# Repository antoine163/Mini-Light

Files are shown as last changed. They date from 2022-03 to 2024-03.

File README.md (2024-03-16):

# Mini Light
This is a small brightness control for desktop / workbench  / ... 
This is composed several parts:
- The control box: To enclose the power supply/electronic and sliders control.
- Light support for shelf: To attach the lights under shelf.
- Light support for prusa: To attach the lights  on prusa 3D printer.
- Wire Ties: To attach some cables.

## Control box
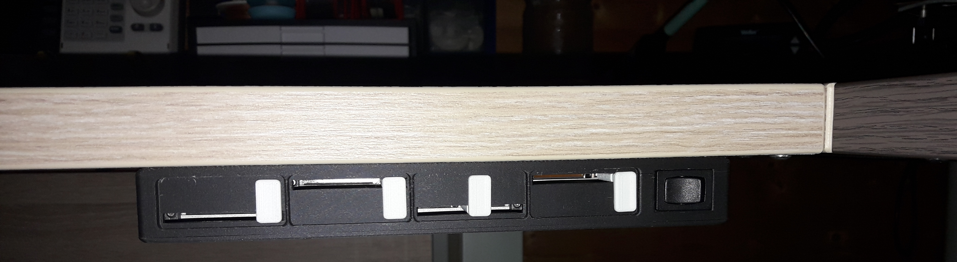
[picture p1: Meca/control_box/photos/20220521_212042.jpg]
 
For more detail see: [Meca/control_box/README.md](Meca/control_box/README.md) 

## Light support for shelf
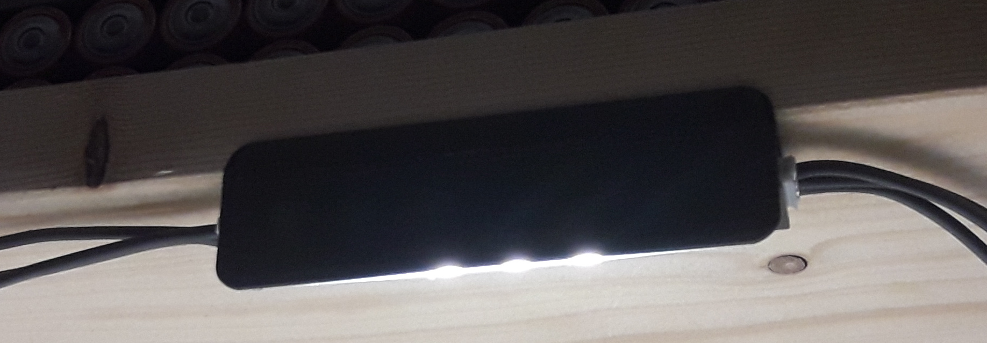
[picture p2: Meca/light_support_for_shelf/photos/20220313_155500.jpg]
 
For more detail see: [Meca/light_support_for_shelf/README.md](Meca/light_support_for_shelf/README.md) 

## Light support for prusa
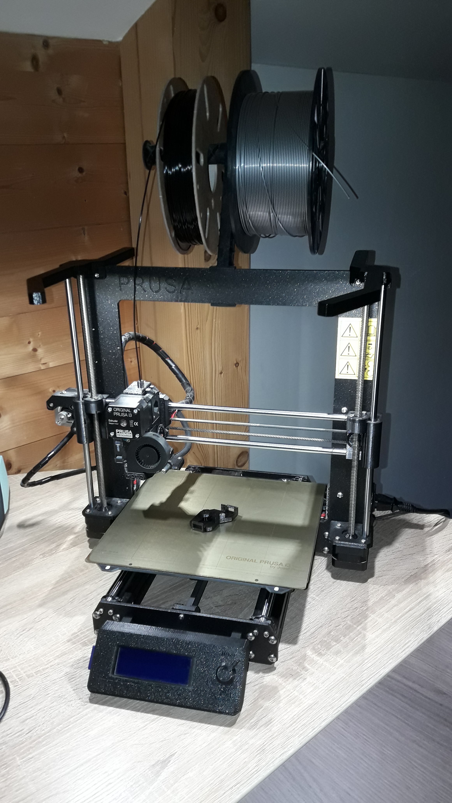
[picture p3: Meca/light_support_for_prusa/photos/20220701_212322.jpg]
 
For more detail see: [Meca/light_support_for_shelf/README.md](Meca/light_support_for_prusa/README.md) 

# 3D Models
Some 3D models are not included in this project. You will need to download them from the manufacturers website if you need them.

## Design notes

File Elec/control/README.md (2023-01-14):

# Mini-Light-Control Board
This board can be power and control 4 different cluster of mini_light board.

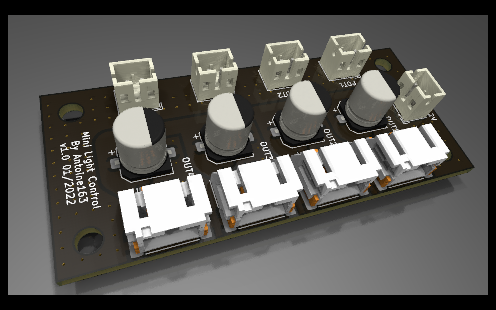
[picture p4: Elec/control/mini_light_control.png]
mini_light_control
 

# Schematic


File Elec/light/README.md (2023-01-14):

# Mini-Light Board
This board is a mini_light board.

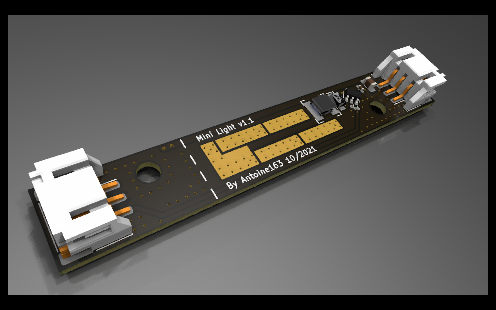
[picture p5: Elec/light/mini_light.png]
mini_light_control
 

Consumption max: 1.8W 

# Schematic


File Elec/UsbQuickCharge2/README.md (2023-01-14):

# Usb Quick Charge 2.0

Circuit To enables 12V power on a USB Quick Charge 2.0 interface.
And brightness adjustment for Mini-Light.

# Schematic


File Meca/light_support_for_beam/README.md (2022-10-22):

# Mini light: Light support for beam
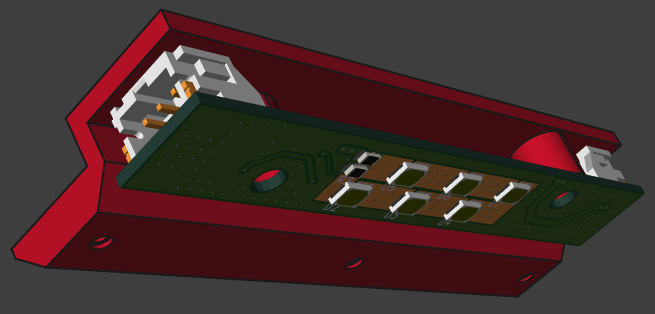
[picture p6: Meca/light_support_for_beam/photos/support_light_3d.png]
Front view
 

## How to build
### List of items to found
- Some wires: [Amazon](https://www.amazon.fr/gp/product/B07G72FZCR/ref=ppx_od_dt_b_asin_title_s00?ie=UTF8&psc=1), [Farnell](https://fr.farnell.com/lapp-kabel/0047001/fil-silicone-0-25mm-noir-100m/dp/1285908) 
- Some JST connectors, PH series: [Amazon](https://www.amazon.fr/gp/product/B07SN5DLWH/ref=ppx_od_dt_b_asin_title_s00?ie=UTF8&psc=1)
- Some M3 threaded inser: [Amazon](https://www.amazon.fr/gp/product/B08BCRZZS3/ref=ppx_yo_dt_b_asin_title_o02_s00?ie=UTF8&psc=1)
- Some M3 Screws: [Amazon](https://www.amazon.fr/gp/product/B07ZF2SDW6/ref=ppx_yo_dt_b_asin_title_o00_s00?ie=UTF8&psc=1)

### List of board to build
- 1x light board. See: [Elec/light/README.md](../../Elec/light/README.md) 

### List of 3D printed parts
- 1x support_light

All 3D parts in .stl format are in to **"stl"** folder. In the folder **"prusa-slicer"** you can found the project of prusa-slicer.

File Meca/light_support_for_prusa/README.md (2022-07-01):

# Mini light: Light support for prusa mk3
Front view 
**Note:** The fixing is inspired by the prject [LED Light Bar Prusa i3 MK2/MK3](https://www.printables.com/fr/model/3267-led-light-bar-prusa-i3-mk2mk3) 

## How to build
### List of items to found
- Some wires: [Amazon](https://www.amazon.fr/gp/product/B07G72FZCR/ref=ppx_od_dt_b_asin_title_s00?ie=UTF8&psc=1), [Farnell](https://fr.farnell.com/lapp-kabel/0047001/fil-silicone-0-25mm-noir-100m/dp/1285908) 
- Some JST connectors, PH series: [Amazon](https://www.amazon.fr/gp/product/B07SN5DLWH/ref=ppx_od_dt_b_asin_title_s00?ie=UTF8&psc=1)
- Some M3 threaded inser: [Amazon](https://www.amazon.fr/gp/product/B08BCRZZS3/ref=ppx_yo_dt_b_asin_title_o02_s00?ie=UTF8&psc=1)
- Some M3 Screws: [Amazon](https://www.amazon.fr/gp/product/B07ZF2SDW6/ref=ppx_yo_dt_b_asin_title_o00_s00?ie=UTF8&psc=1)

### List of board to build
- 4x light boards. See: [Elec/light/README.md](../../Elec/light/README.md) 

### List of 3D printed parts
- 1x support_light_l.stl
- 1x support_light_nut_r.stl
- 1x support_light_nut_l.stl
- 1x support_light_r.stl

All 3D parts in .stl format are in to **"stl"** folder. In the folder **"prusa-slicer"** you can found the project of prusa-slicer.

## Photo to help build
### List of wire to cut
- 6x 2cm
- 6x 14cm
- 3x 32cm

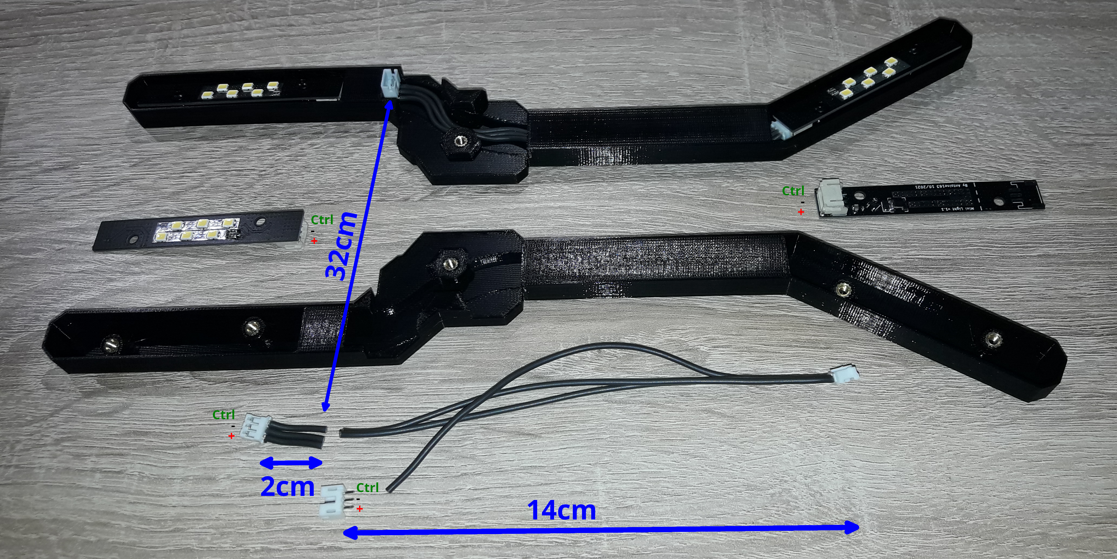
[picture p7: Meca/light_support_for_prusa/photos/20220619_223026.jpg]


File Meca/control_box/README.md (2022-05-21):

# Mini light: Control box
Front view 
Another view with a slider (control_box-AsPotsCap) in v1:
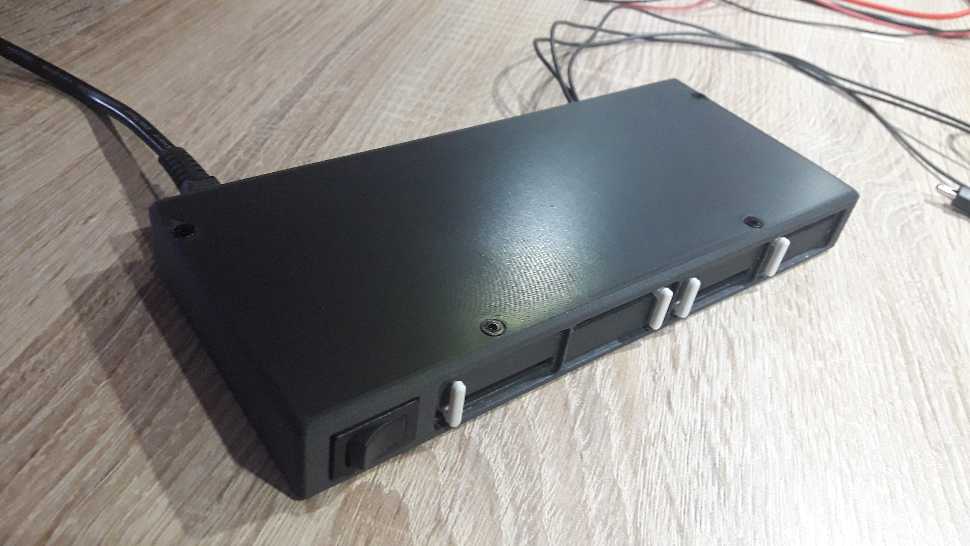
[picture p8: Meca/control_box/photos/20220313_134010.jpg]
 
## How to build
### List of items to found
- 1x IEC320 C7 cable.
- 1x IEC320 C7 connecter: [Amazon](https://www.amazon.fr/gp/product/B08TWM1LQ6/ref=ppx_yo_dt_b_asin_title_o00_s00?ie=UTF8&psc=1) 
- 1x Toggle Swith 230V (Multicomp: MP004405): [Farnell](https://fr.farnell.com/multicomp-pro/mp004405/commut-spst-10a-250vac-noir-panneau/dp/3462082) 
- 1x 230V to 12V Power module: [Amazon](https://www.amazon.fr/gp/product/B0924XBMCF/ref=ppx_yo_dt_b_asin_title_o01_s00?ie=UTF8&th=1) 
- 1x to 4x 50K slide potentiometers (Alps Alpine: STRS30102K): [Farnell](https://fr.farnell.com/alps/strs30102k/potentiometre-slide-50k/dp/1191729) 
- Some wires: [Amazon](https://www.amazon.fr/gp/product/B07G72FZCR/ref=ppx_od_dt_b_asin_title_s00?ie=UTF8&psc=1), [Farnell](https://fr.farnell.com/lapp-kabel/0047001/fil-silicone-0-25mm-noir-100m/dp/1285908) , **Note**: For wires connected at sector power use appropriate wires, I don't sure that wire is usable for this!
- Some JST connectors, PH series: [Amazon](https://www.amazon.fr/gp/product/B07SN5DLWH/ref=ppx_od_dt_b_asin_title_s00?ie=UTF8&psc=1), **Note**: The box for SMT is unavailable now
- Some M3 threaded inser: [Amazon](https://www.amazon.fr/gp/product/B08BCRZZS3/ref=ppx_yo_dt_b_asin_title_o02_s00?ie=UTF8&psc=1)
- Some M3 Screws: [Amazon](https://www.amazon.fr/gp/product/B07ZF2SDW6/ref=ppx_yo_dt_b_asin_title_o00_s00?ie=UTF8&psc=1)
- Some M2 Screws and nut: [Amazon](https://www.amazon.fr/gp/product/B093BY1XJJ/ref=ppx_yo_dt_b_asin_title_o02_s00?ie=UTF8&psc=1)

### List of board to build
- 1x Mini light control board. See: [Elec/control/README.md](../../Elec/control/README.md) 

### List of 3D printed parts
- 1x control_box-AsPotsCap_v2 (or control_box-AsPotsCap)
- 1x control_box-control_box
- 1x control_box-control_box_lid
- 1x control_box-Fix1_Power_Supply
- 1x control_box-Fix2_Power_Supply
- 4x control_box-SupPot

All 3D parts in .stl format are in to **"stl"** folder. In the folder **"prusa-slicer"** you can found the project of prusa-slicer.

## Photos to help build
**Note**: One the photos below there are only two sliders connected and control_box-AsPotsCap is in v1.
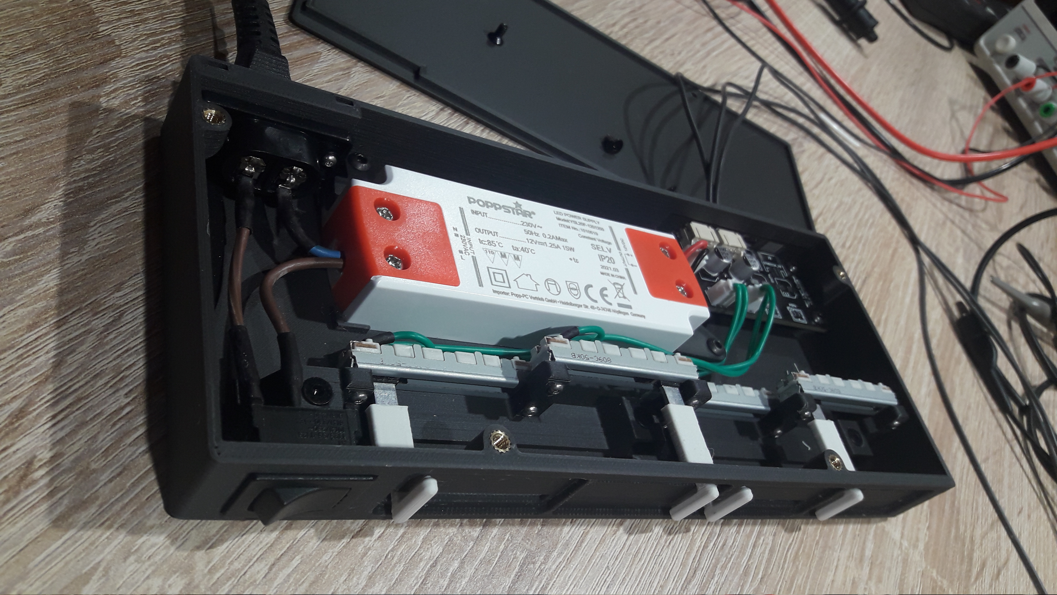
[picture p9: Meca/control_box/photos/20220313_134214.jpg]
 
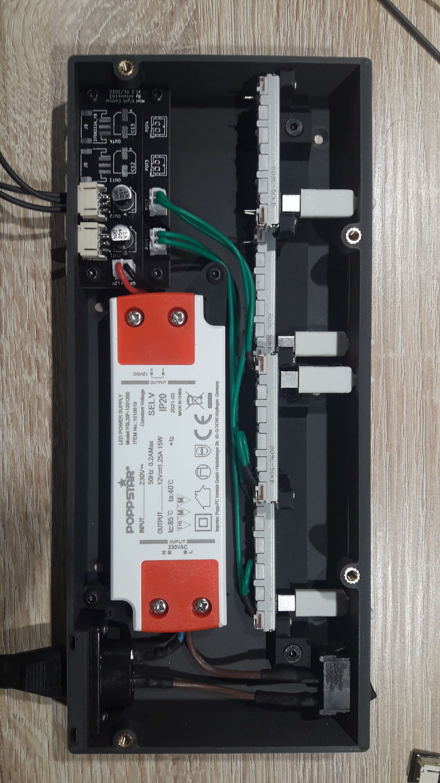
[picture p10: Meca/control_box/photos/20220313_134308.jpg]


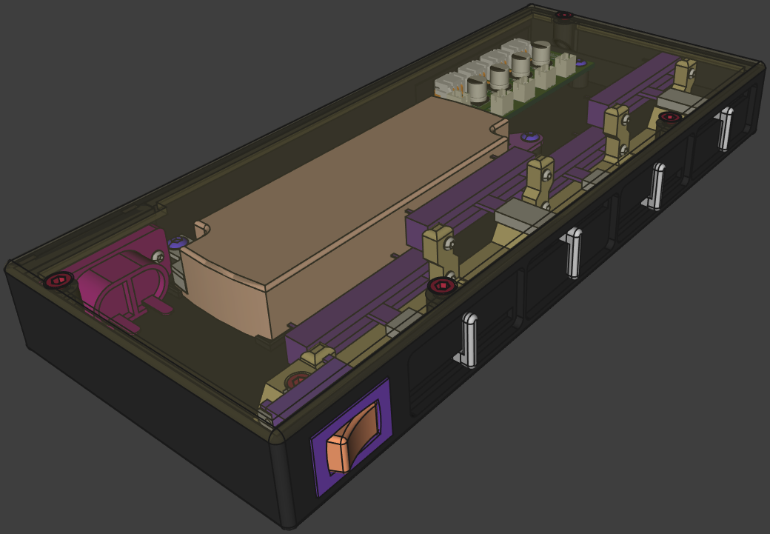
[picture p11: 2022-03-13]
Meca/control_box/front_view.png

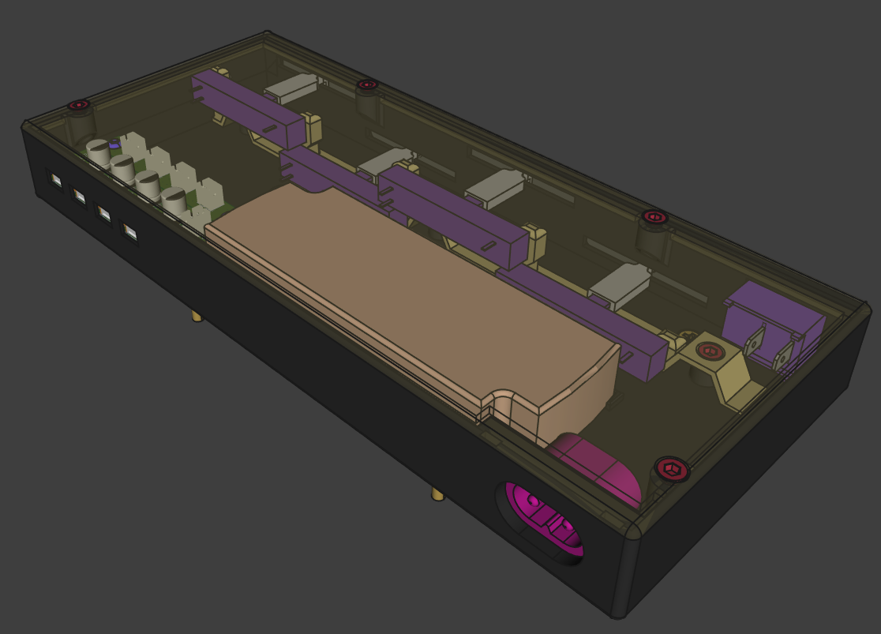
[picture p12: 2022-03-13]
Meca/control_box/rear_view.png

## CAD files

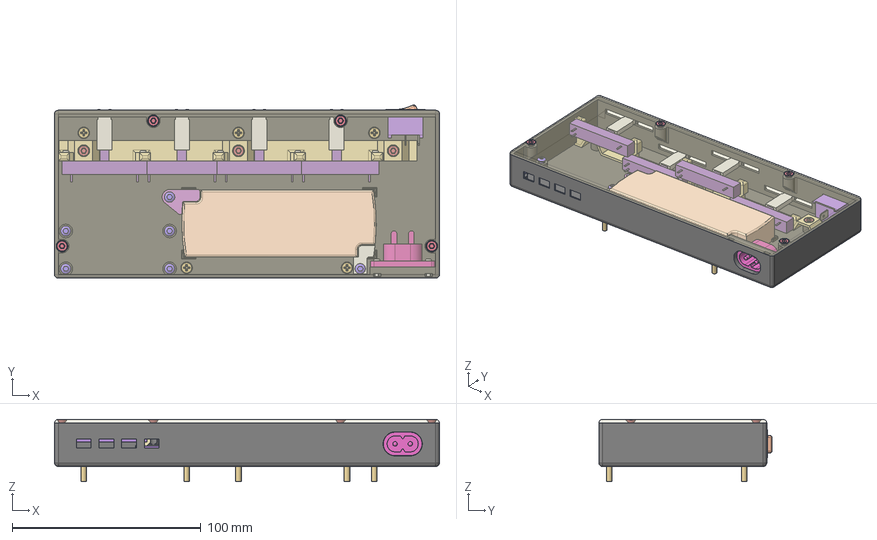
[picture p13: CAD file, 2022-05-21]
Meca/control_box/control_box.FCStd
204.0 x 91.9 x 33.0 mm
Poppstar_Power_Supply
conn1 x 2
switche
SupPot
Cap_1 x 4
STRS30102K_1 x 4
M2x6 x 8
Fix1_Power_Supply
Fix2_Power_Supply
IEC320_C7
M2x8 x 2
M3x10_Wood x 5
M3x4_Flat x 7
M3x6_Button x 6
control_box
control_box_lid

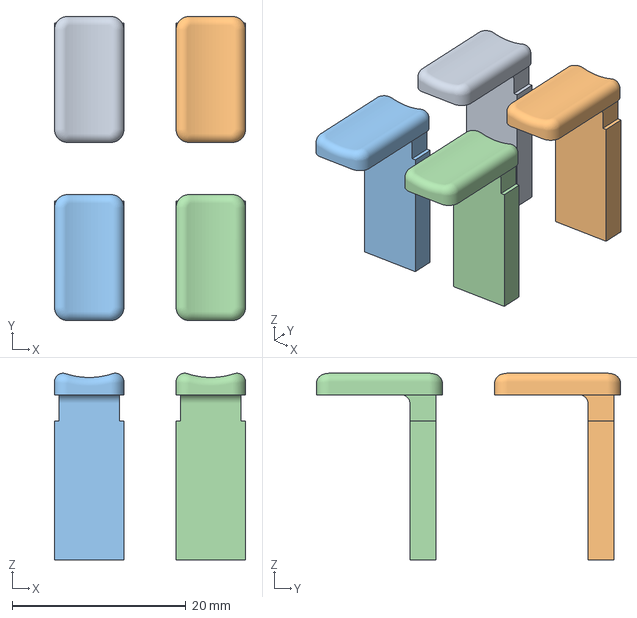
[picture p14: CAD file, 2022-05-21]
Meca/control_box/prusa-slicer/control_box-AsPotsCap_v2.3mf
22.0 x 35.0 x 21.5 mm

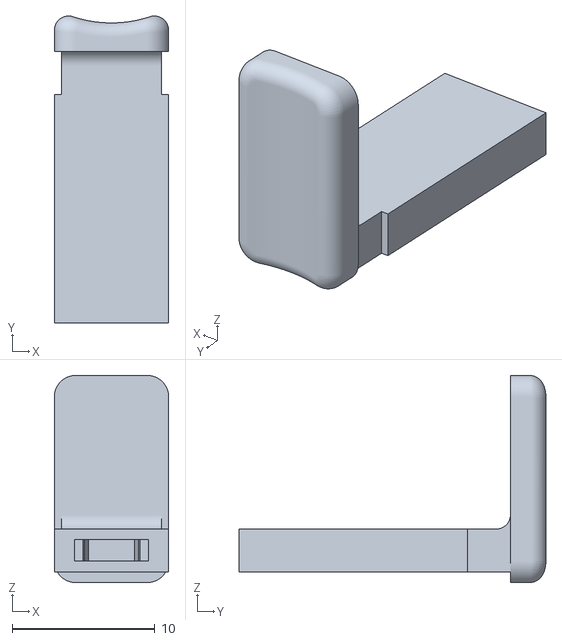
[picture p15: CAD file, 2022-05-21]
Meca/control_box/stl/control_box-AsPotsCap_v2.stl
8.00 x 21.5 x 14.5

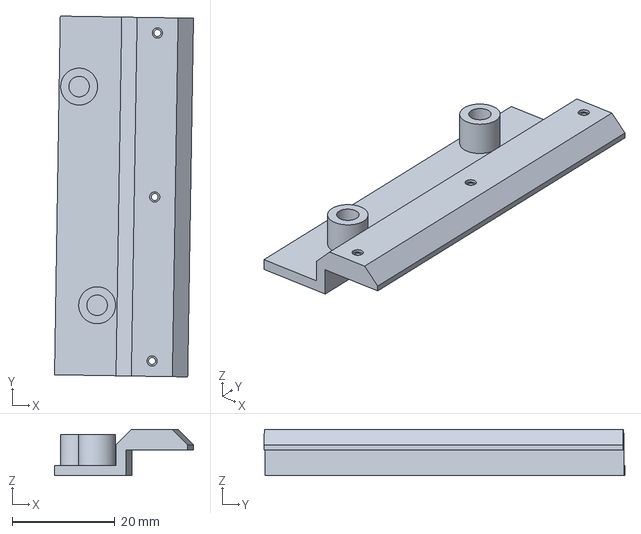
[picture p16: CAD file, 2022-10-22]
Meca/light_support_for_beam/prusa-slicer/support_light.3mf
27.1 x 70.4 x 9.00 mm

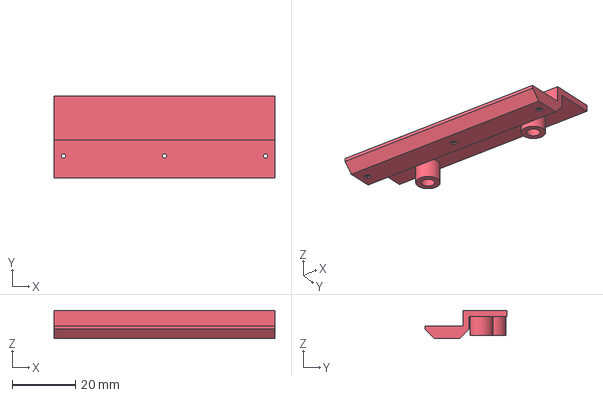
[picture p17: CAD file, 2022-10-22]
Meca/light_support_for_beam/support_light.FCStd
70.0 x 26.0 x 9.00 mm

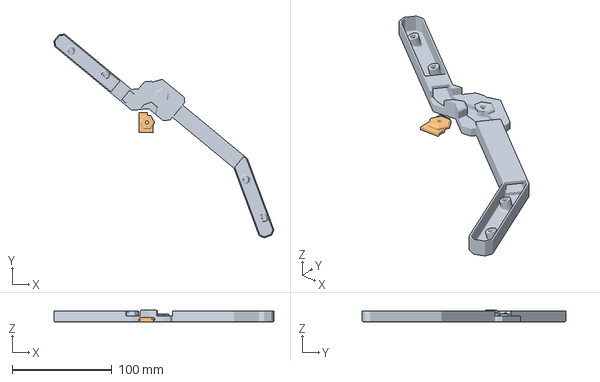
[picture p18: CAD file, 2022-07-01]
Meca/light_support_for_prusa/prusa-slicer/support_light_l.3mf
220.4 x 204.2 x 12.1 mm
support_light_l.stl
support_light_nut_l.stl

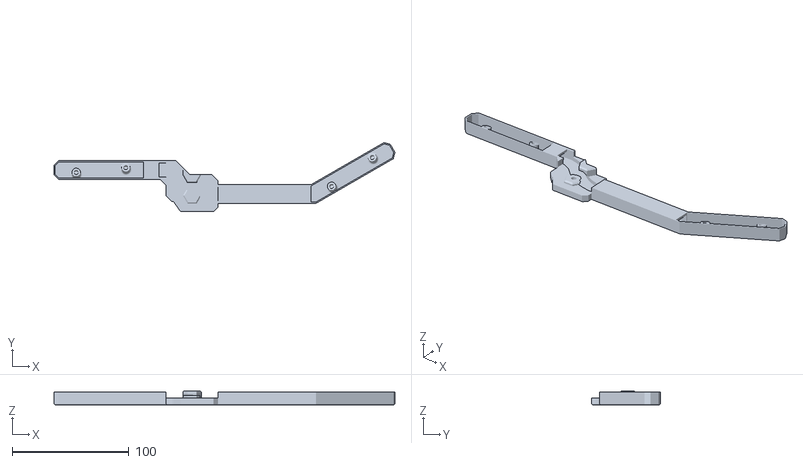
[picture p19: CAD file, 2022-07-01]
Meca/light_support_for_prusa/stl/support_light_r.stl
292.1 x 59.0 x 12.1

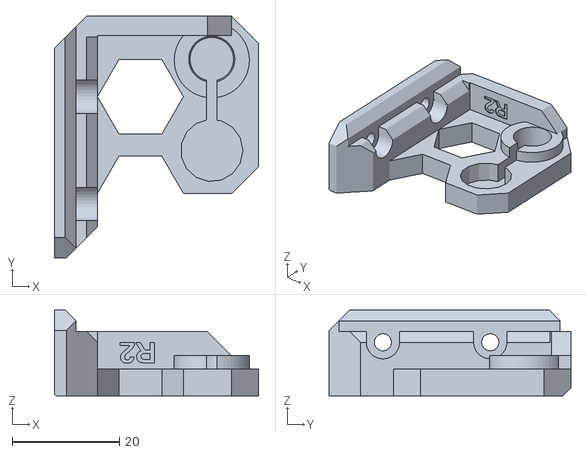
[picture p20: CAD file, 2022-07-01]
Meca/light_support_for_prusa/z-axis-top_l.stl
38.0 x 45.0 x 16.0

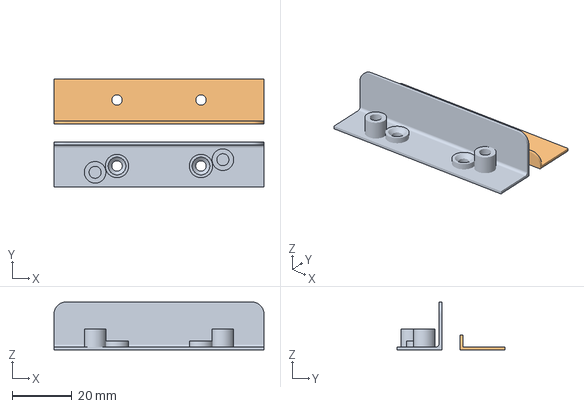
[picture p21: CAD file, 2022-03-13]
Meca/light_support_for_shelf/prusa-slicer/support_light.3mf
70.0 x 36.0 x 16.0 mm
support_light_part1.stl
support_light_part2.stl

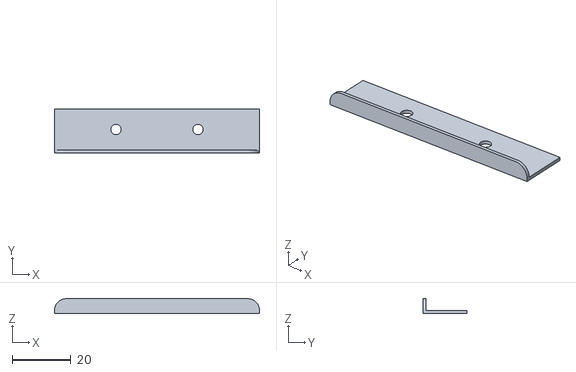
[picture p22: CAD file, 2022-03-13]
Meca/light_support_for_shelf/stl/support_light_part2.stl
70.0 x 15.0 x 5.00

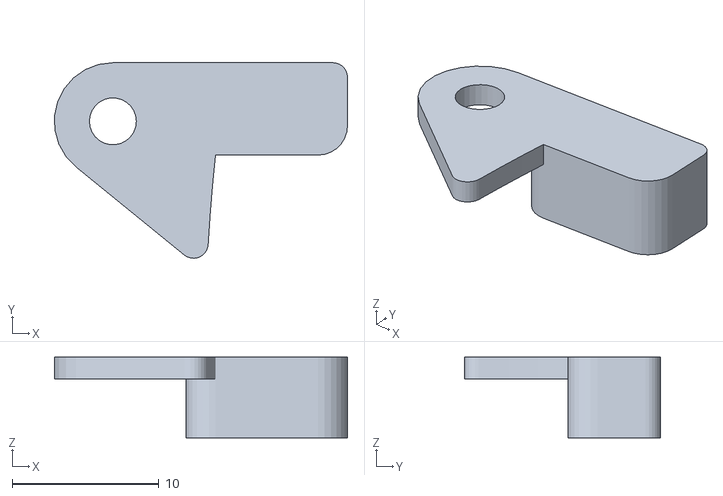
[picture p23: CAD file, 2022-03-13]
Meca/control_box/stl/control_box-Fix1_Power_Supply.stl
20.0 x 13.3 x 5.50

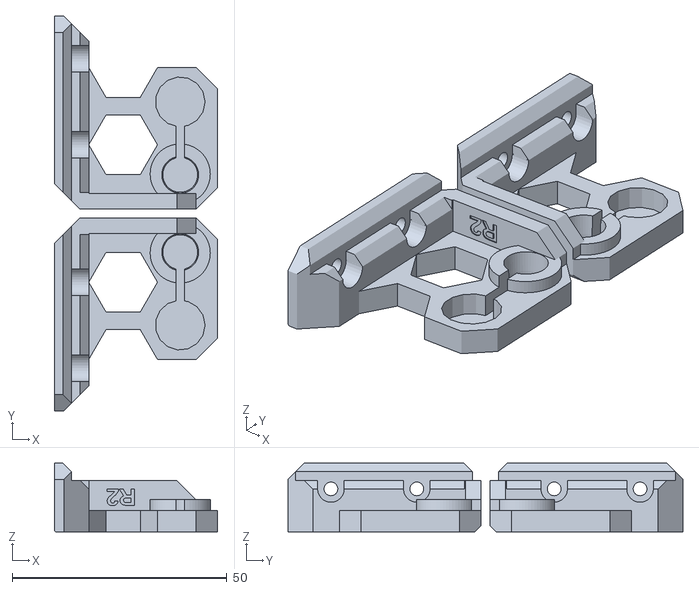
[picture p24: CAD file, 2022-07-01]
Meca/light_support_for_prusa/z-axis-top.stl
38.0 x 92.0 x 16.0

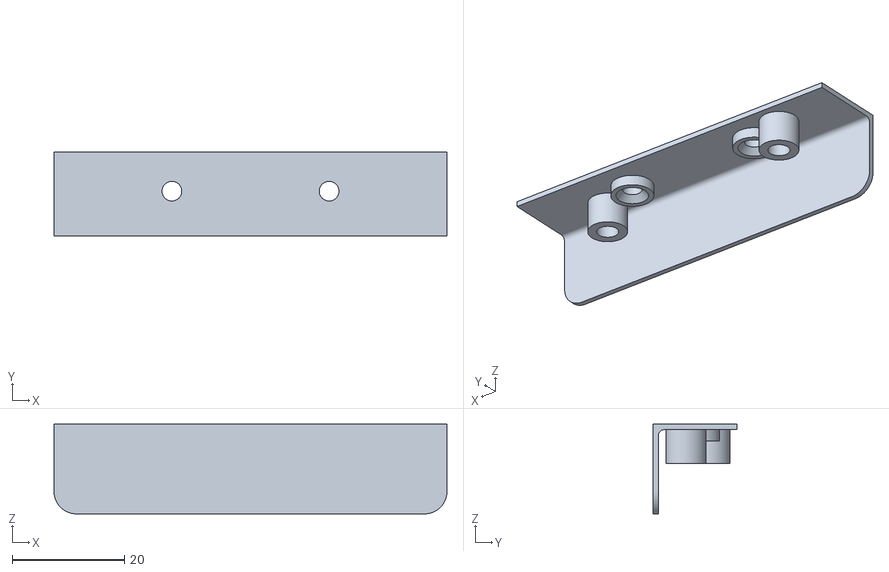
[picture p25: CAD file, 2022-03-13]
Meca/light_support_for_shelf/stl/support_light_part1.stl
70.0 x 15.0 x 16.0

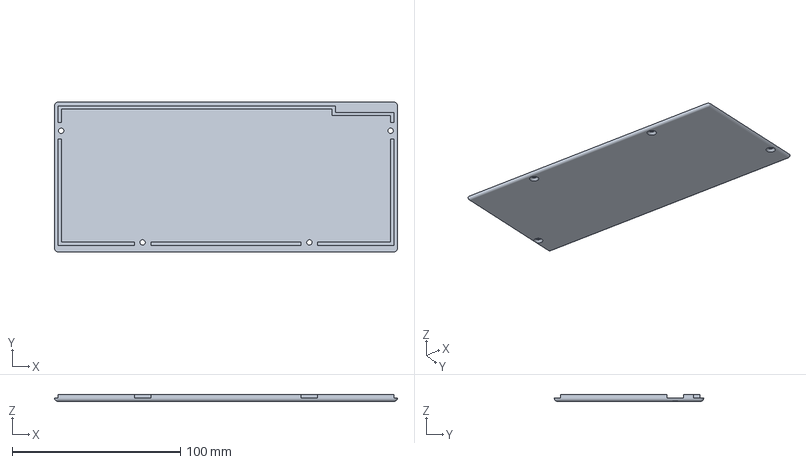
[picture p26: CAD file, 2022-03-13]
Meca/control_box/prusa-slicer/control_box-control_box_lid.3mf
204.0 x 89.0 x 4.00 mm

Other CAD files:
Meca/light_support_for_prusa/prusa-slicer/support_light_r.3mf
Meca/control_box/stl/control_box-control_box_lid.stl
Meca/light_support_for_prusa/z-axis-top_r.stl
Meca/control_box/prusa-slicer/control_box-control_box.3mf
Meca/control_box/prusa-slicer/control_box-AsPotsCap.3mf
Meca/control_box/prusa-slicer/control_box-Fix_Power_Supply.3mf
Meca/control_box/prusa-slicer/control_box-SupPot.3mf
Meca/control_box/stl/control_box-AsPotsCap.stl
Meca/control_box/stl/control_box-Fix2_Power_Supply.stl
Meca/control_box/stl/control_box-SupPot.stl
Meca/control_box/stl/control_box-control_box.stl
Meca/light_support_for_beam/stl/support_light.stl
Meca/light_support_for_prusa/mini_light.step
Meca/light_support_for_prusa/stl/support_light_l.stl
Meca/light_support_for_prusa/stl/support_light_nut_l.stl
Meca/light_support_for_prusa/stl/support_light_nut_r.stl
Meca/light_support_for_shelf/support_light.FCStd

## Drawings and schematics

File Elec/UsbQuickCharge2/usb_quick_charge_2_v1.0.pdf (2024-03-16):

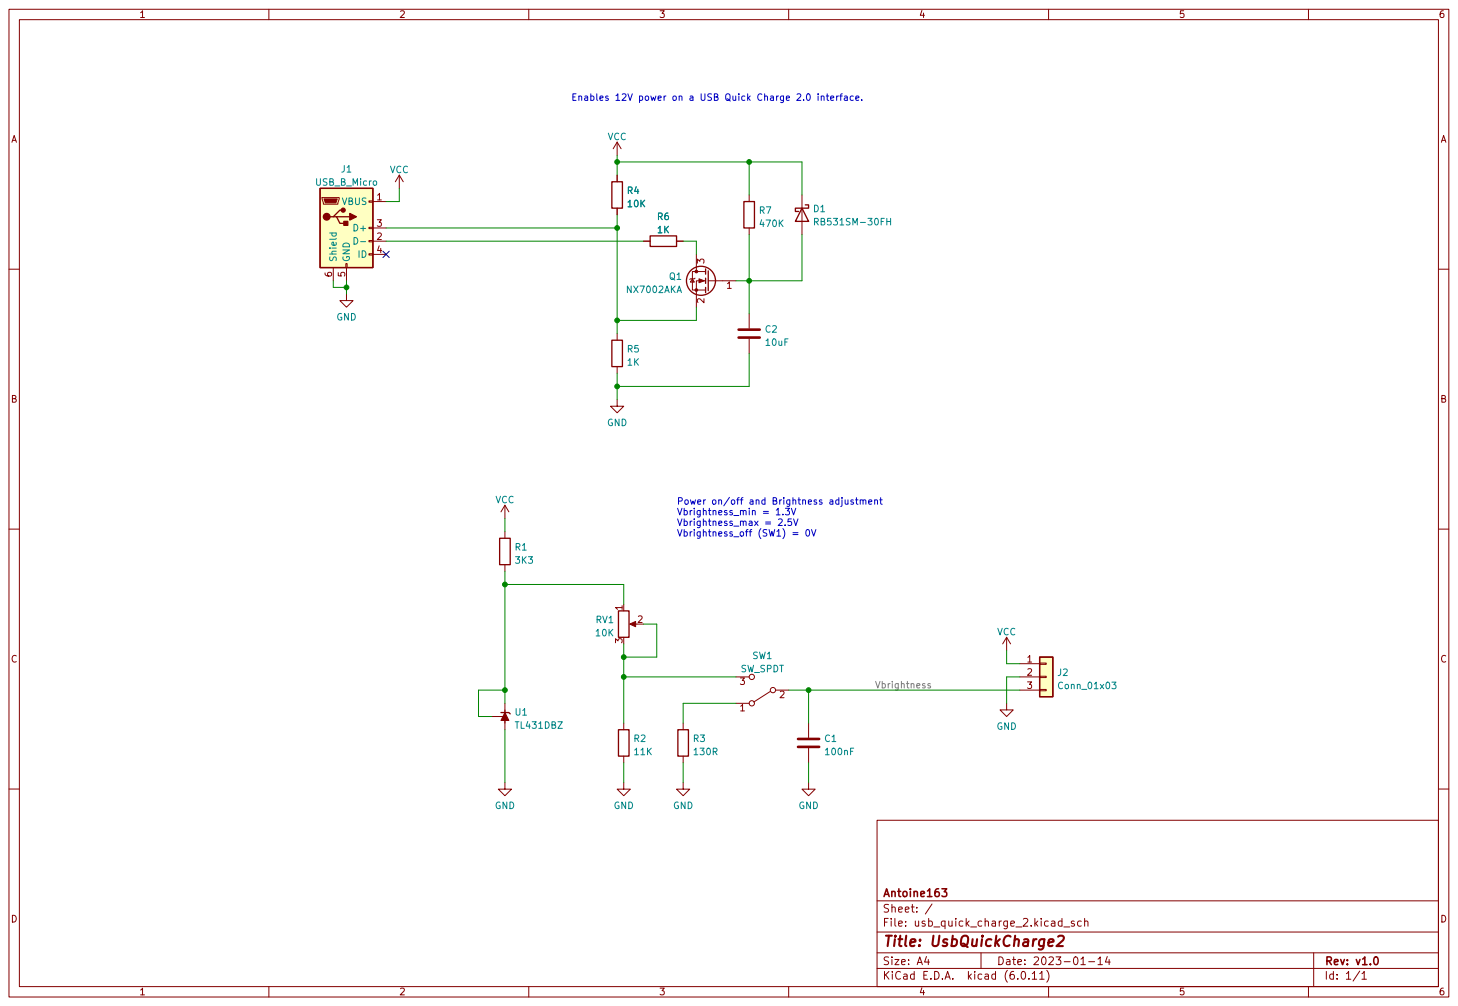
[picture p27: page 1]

Enables 12V power on a USB Quick Charge 2.0 interface. R6

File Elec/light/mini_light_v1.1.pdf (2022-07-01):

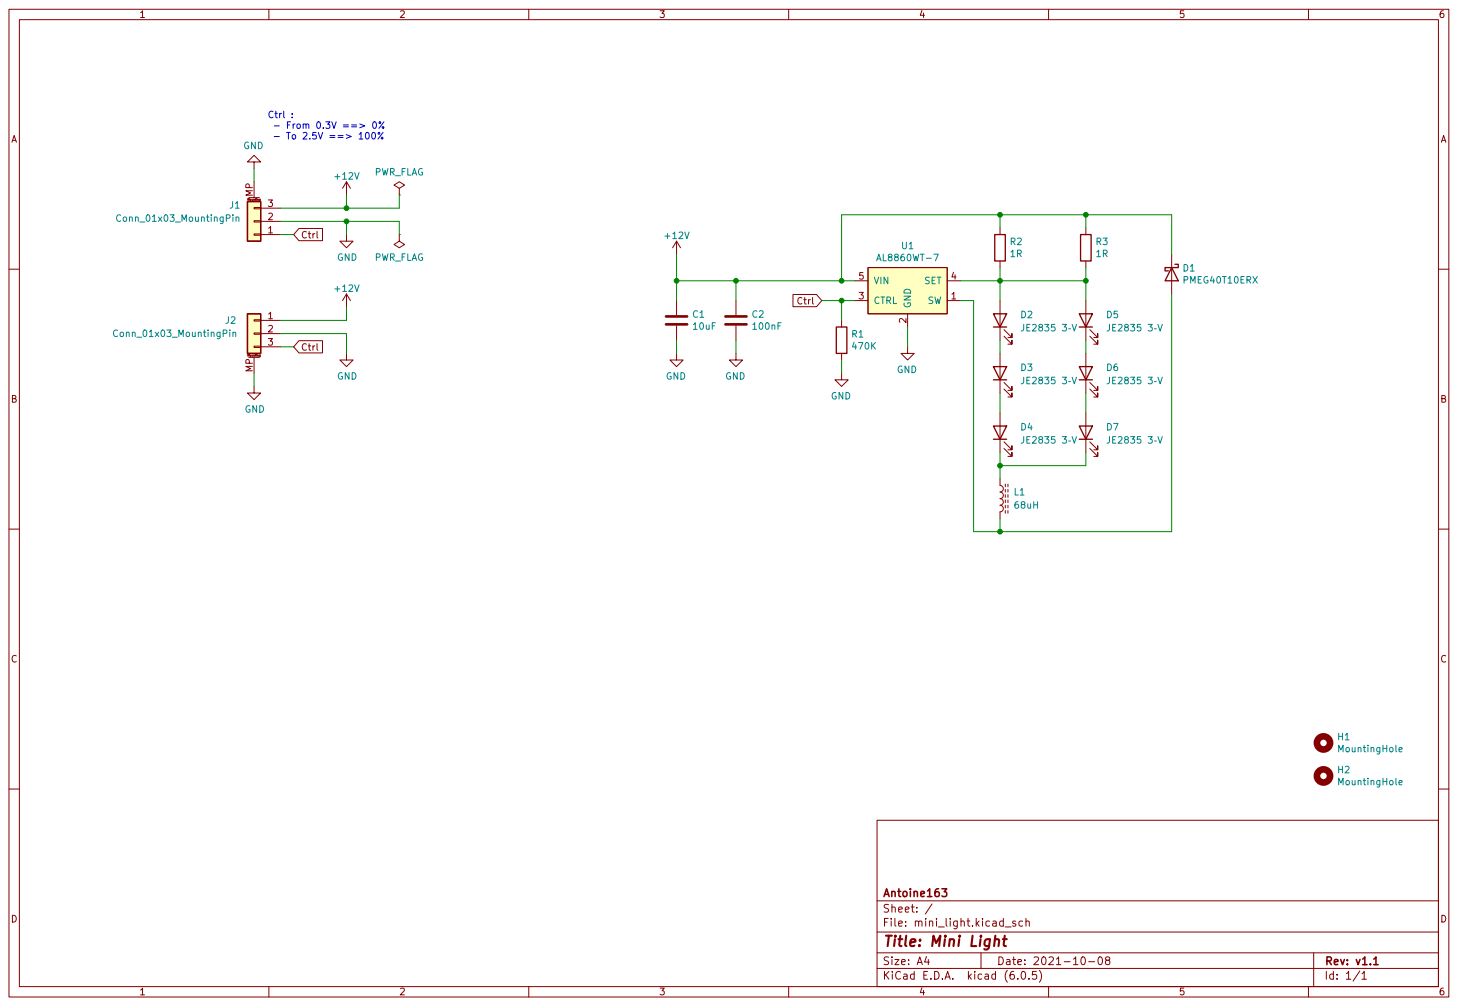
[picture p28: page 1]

2 CTRL 3 SET 4 VIN 5 U1 AL8860WT-7 GND

Id: 1/1 Title: Mini Light

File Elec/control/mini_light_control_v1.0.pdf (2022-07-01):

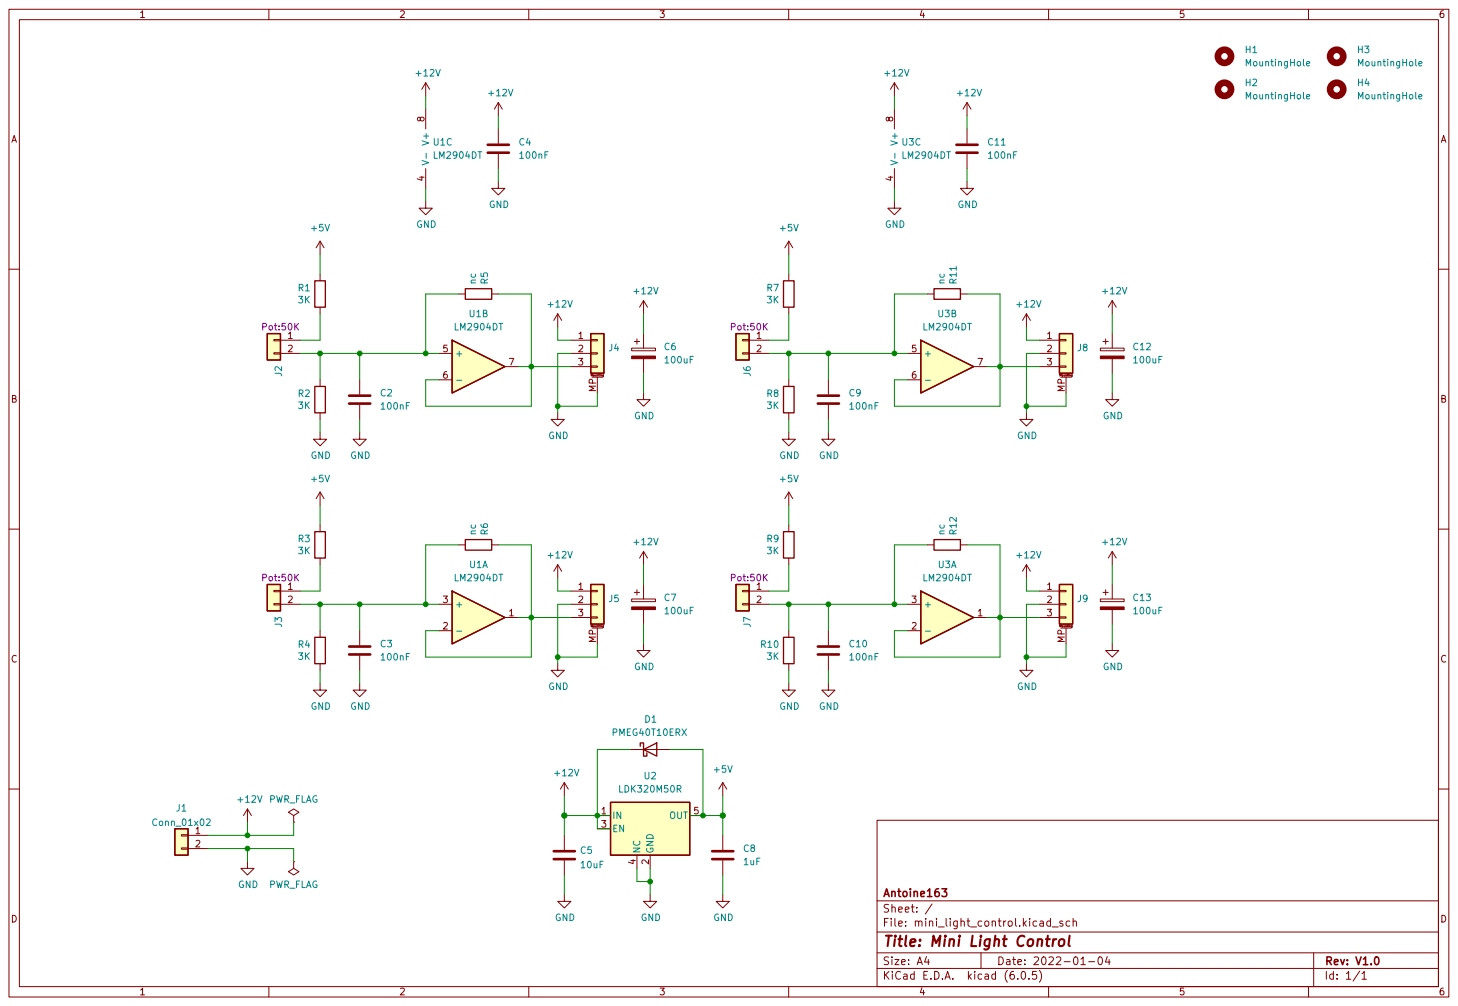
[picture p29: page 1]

Id: 1/1 Title: Mini Light Control

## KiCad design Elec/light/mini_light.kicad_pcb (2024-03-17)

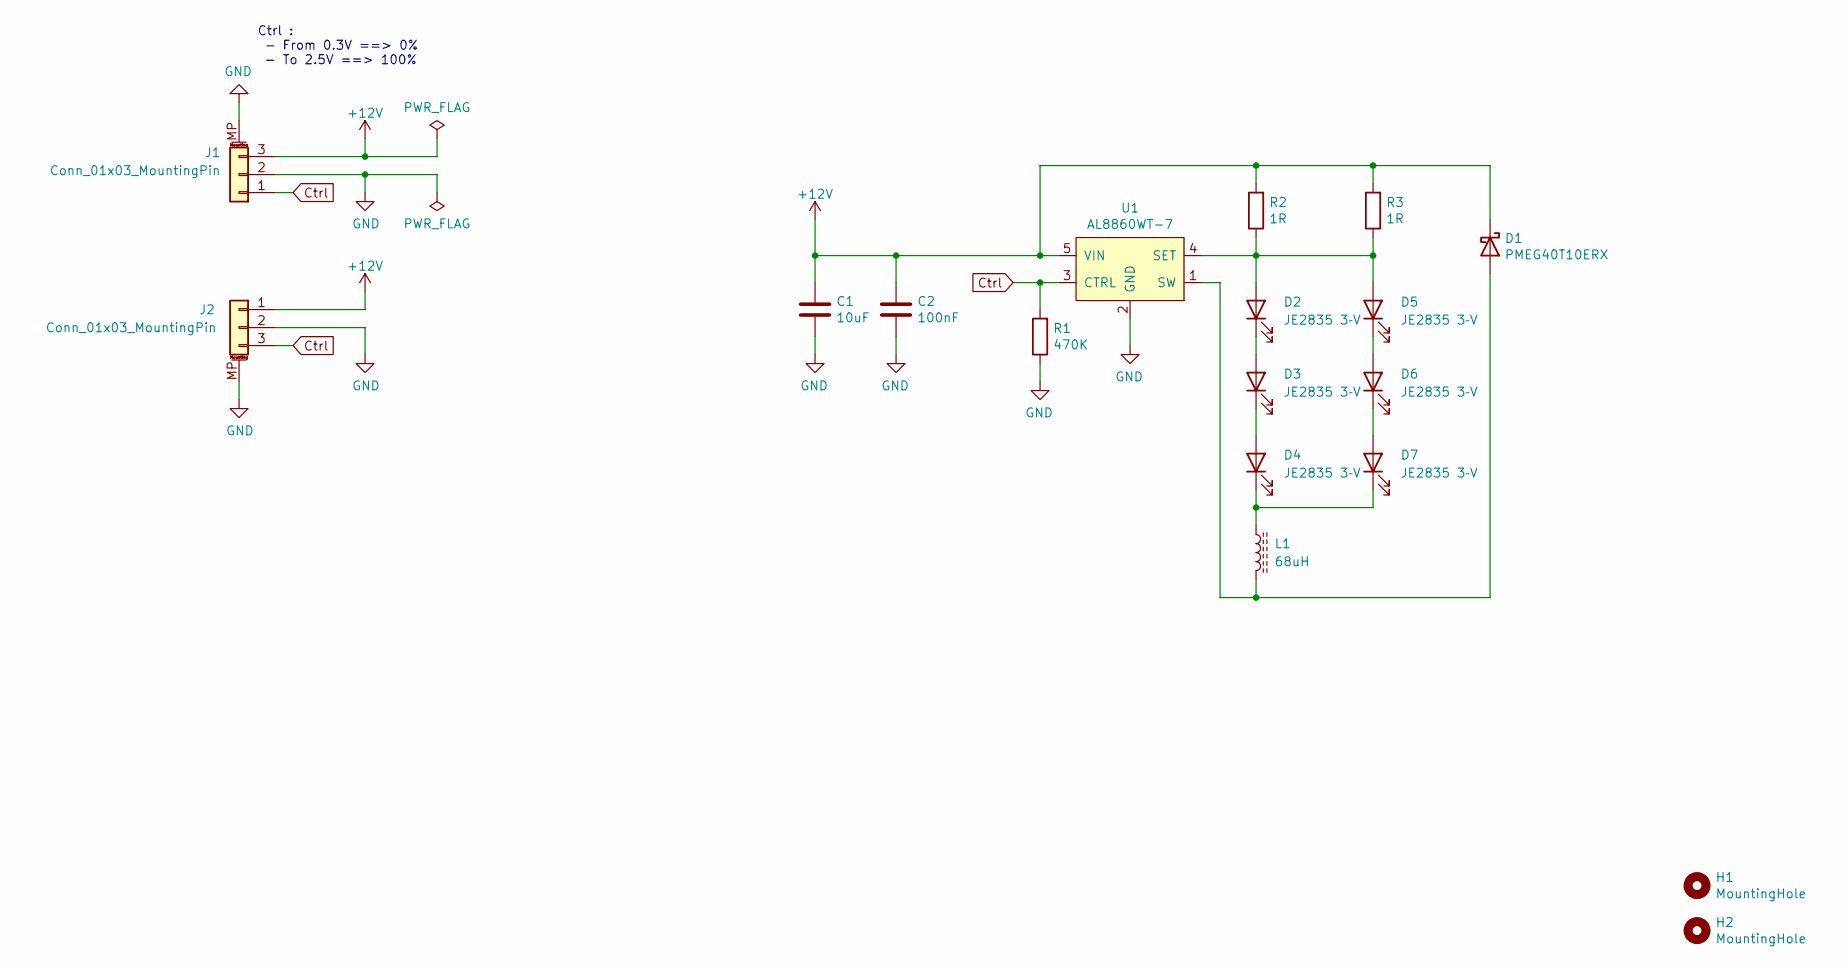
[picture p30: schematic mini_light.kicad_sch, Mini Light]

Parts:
C1: 10uF; C_0805_2012Metric_Pad1.18x1.45mm_HandSolder
C2: 100nF; C_0402_1005Metric_Pad0.74x0.62mm_HandSolder
D1: PMEG40T10ERX; Nexperia_CFP3_SOD-123W
D2, D3, D4, D5, D6, D7: JE2835 3‑V; LED_Cree-JE
H1, H2: MountingHole; MountingHole_3.2mm_M3
J1, J2: Conn_01x03_MountingPin; JST_PH_S3B-PH-SM4-TB_1x03-1MP_P2.00mm_Horizontal
L1: 68uH; L_Bourns-SRN5040
R1: 470K; R_0402_1005Metric_Pad0.72x0.64mm_HandSolder
R2, R3: 1R; R_0805_2012Metric_Pad1.20x1.40mm_HandSolder
U1: AL8860WT-7; TSOT-23-5

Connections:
+12V: C1.1, C2.1, D1.1 (K), J1.3, J2.1, R2.2, R3.2, U1.5 (VIN)
Ctrl: J1.1, J2.3, R1.2, U1.3 (CTRL)
GND: C1.2, C2.2, J1.2, J1.MP (MountPin), J2.2, J2.MP (MountPin), R1.1, U1.2 (GND)
unnamed: D1.2 (A), L1.2, U1.1 (SW)
unnamed: D2.1 (K), D3.2 (A)
unnamed: D2.2 (A), D5.2 (A), R2.1, R3.1, U1.4 (SET)
unnamed: D3.1 (K), D4.2 (A)
unnamed: D4.1 (K), D7.1 (K), L1.1
unnamed: D5.1 (K), D6.2 (A)
unnamed: D6.1 (K), D7.2 (A)

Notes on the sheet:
Ctrl : - From 0.3V ==> 0% - To 2.5V ==> 100%

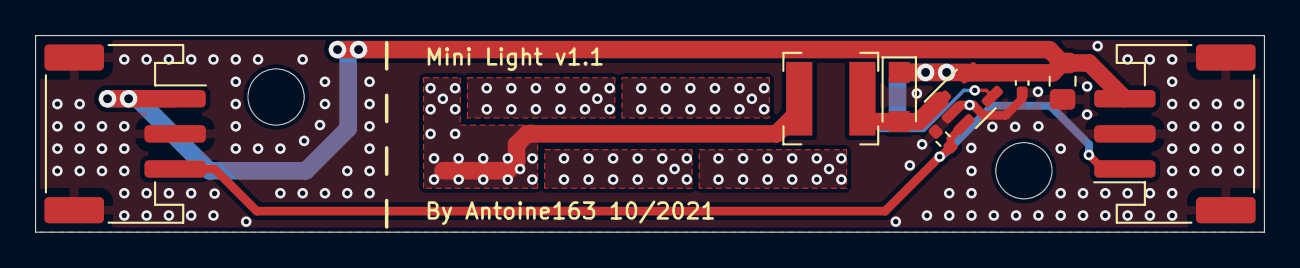
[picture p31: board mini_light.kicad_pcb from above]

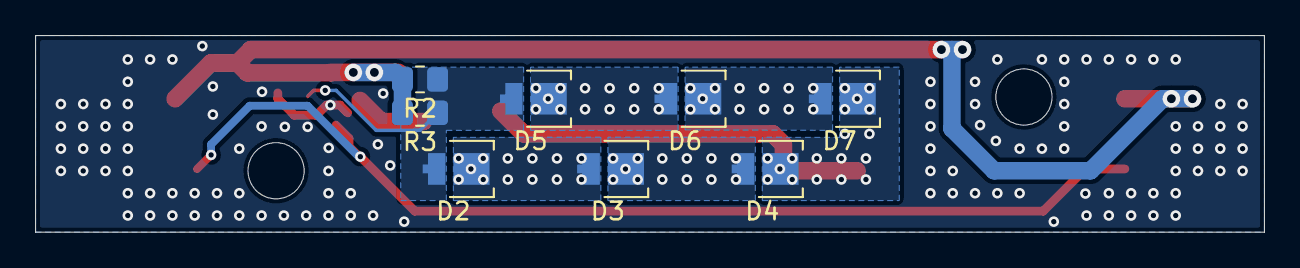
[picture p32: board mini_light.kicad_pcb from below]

Board: 2 copper layers, 70.0 x 11.2 mm, 18 parts (8 on the bottom side), 10 nets.

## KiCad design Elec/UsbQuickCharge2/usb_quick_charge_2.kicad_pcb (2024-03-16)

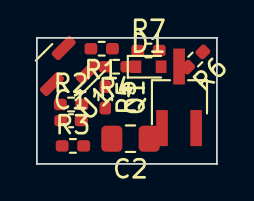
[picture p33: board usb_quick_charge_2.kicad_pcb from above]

Board: 2 copper layers, 10.0 x 7.0 mm, 12 parts (0 on the bottom side), 6 nets, no tracks yet.

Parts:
C1: 100nF; C_0402_1005Metric_Pad0.74x0.62mm_HandSolder
C2: 10uF; C_0805_2012Metric_Pad1.18x1.45mm_HandSolder
D1: RB531SM-30FH; D_SOD-523
Q1: NX7002AKA; TSOT-23_HandSoldering
R1: 2K4; R_0402_1005Metric_Pad0.72x0.64mm_HandSolder
R2: 11K; R_0402_1005Metric_Pad0.72x0.64mm_HandSolder
R3: 130R; R_0402_1005Metric_Pad0.72x0.64mm_HandSolder
R4: 10K; R_0402_1005Metric_Pad0.72x0.64mm_HandSolder
R5, R6: 1K; R_0402_1005Metric_Pad0.72x0.64mm_HandSolder
R7: 470K; R_0402_1005Metric_Pad0.72x0.64mm_HandSolder
U1: TL431DBZ; SOT-23

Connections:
GND: C1.2, C2.2, R2.2, R3.2, R5.2, U1.3 (A)
unnamed: C2.1, D1.2 (A), Q1.1 (G), R7.2
unnamed: Q1.2 (S), R4.2, R5.1
unnamed: Q1.3 (D), R6.2
unnamed: R1.2, U1.1 (K), U1.2 (REF)
VCC: D1.1 (K), R1.1, R4.1, R7.1

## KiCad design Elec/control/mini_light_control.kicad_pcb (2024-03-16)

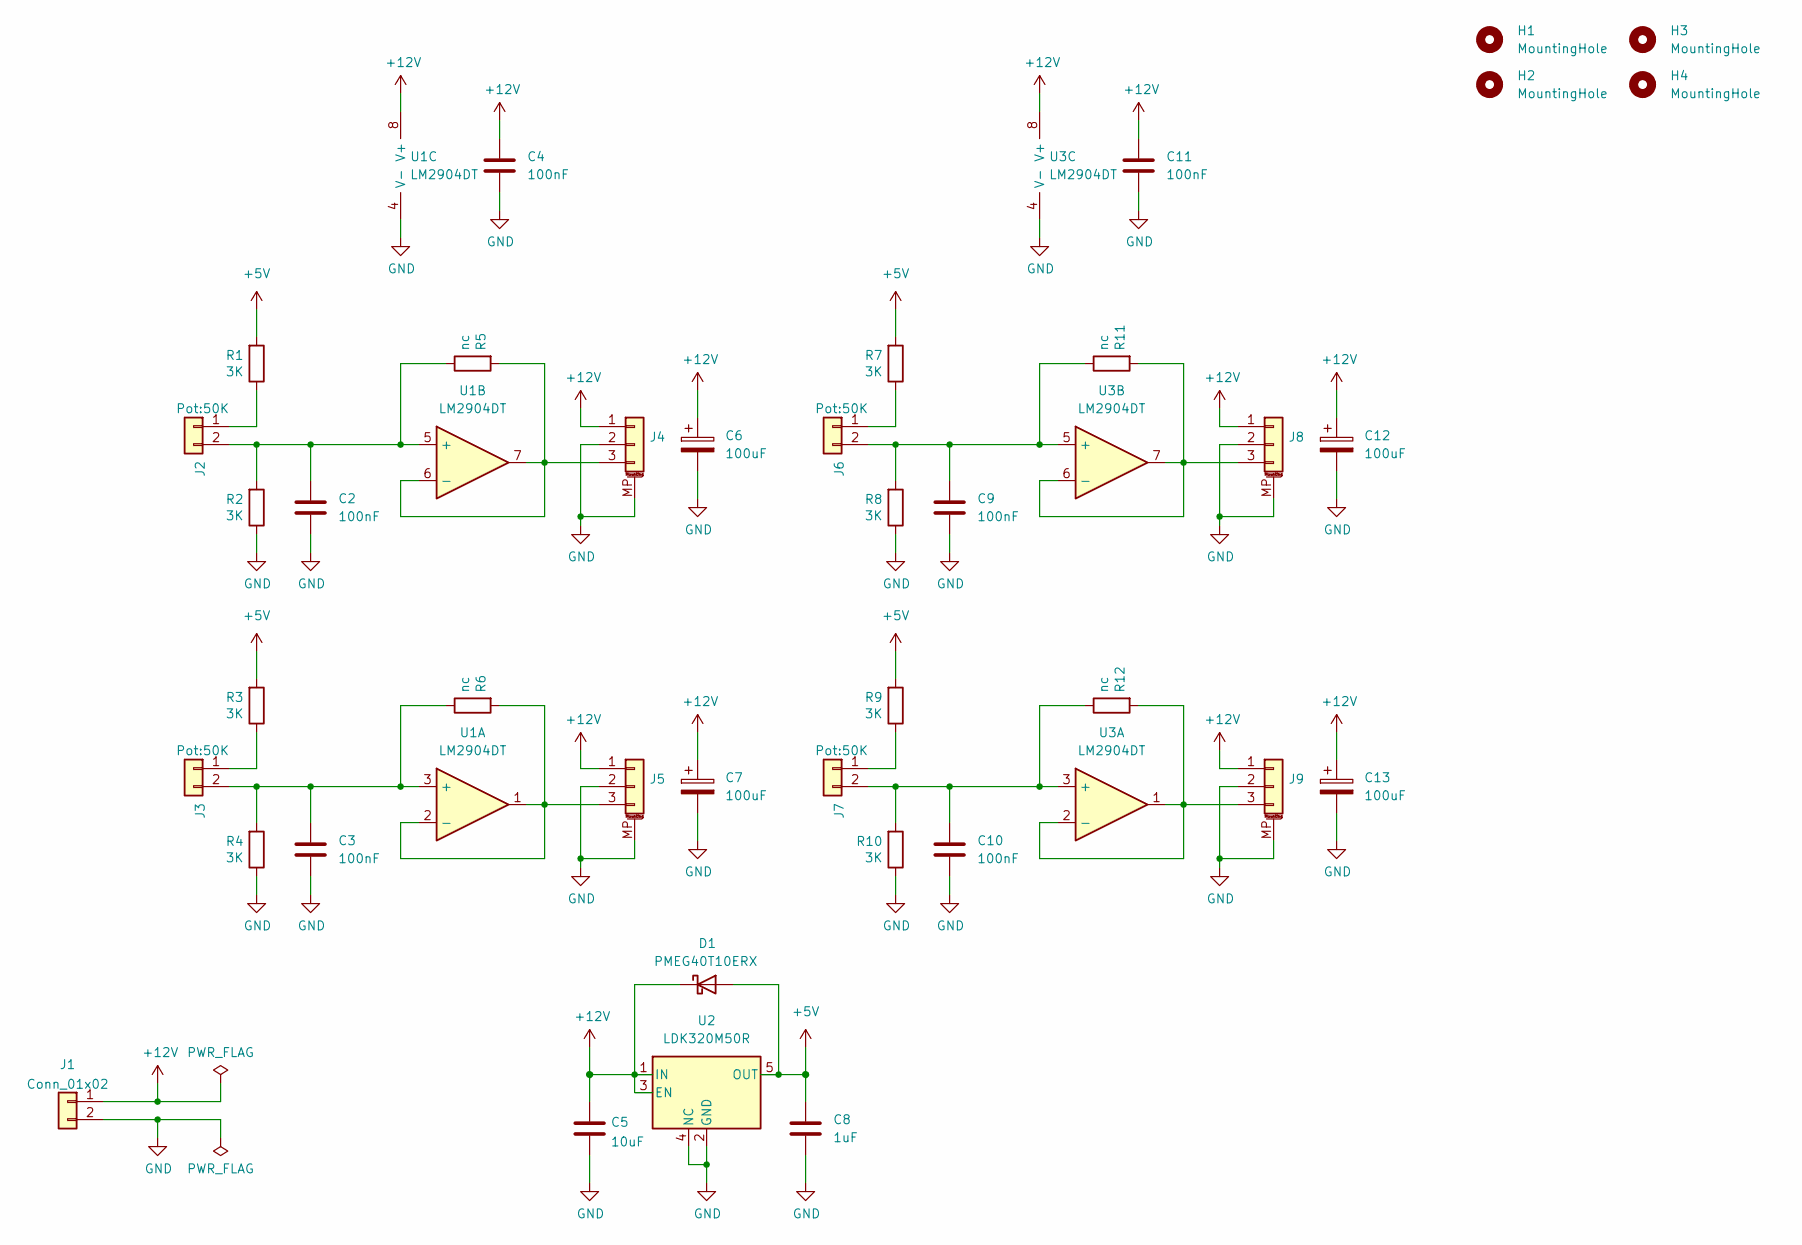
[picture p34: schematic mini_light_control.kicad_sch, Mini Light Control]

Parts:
C2, C3, C4, C9, C10, C11: 100nF; C_0402_1005Metric_Pad0.74x0.62mm_HandSolder
C5: 10uF; C_0805_2012Metric_Pad1.18x1.45mm_HandSolder
C6, C7, C12, C13: 100uF; CP_Elec_6.3x7.7
C8: 1uF; C_0603_1608Metric_Pad1.08x0.95mm_HandSolder
D1: PMEG40T10ERX; Nexperia_CFP3_SOD-123W
H1, H2, H3, H4: MountingHole; MountingHole_3.2mm_M3
J1, J2, J3, J6, J7: Conn_01x02; JST_PH_B2B-PH-K_1x02_P2.00mm_Vertical
J4, J5, J8, J9: Conn_01x03; JST_PH_S3B-PH-SM4-TB_1x03-1MP_P2.00mm_Horizontal
R1, R2, R3, R4, R7, R8, R9, R10: 3K; R_0402_1005Metric_Pad0.72x0.64mm_HandSolder
R5, R6, R11, R12: nc; R_0402_1005Metric_Pad0.72x0.64mm_HandSolder
U1, U3: LM2904DT; SOIC-8_3.9x4.9mm_P1.27mm
U2: LDK320M50R; SOT-23-5

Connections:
+5V: C8.1, D1.2 (A), R1.2, R3.2, R7.2, R9.2, U2.5 (OUT)
+12V: C4.1, C5.1, C6.1, C7.1, C11.1, C12.1, C13.1, D1.1 (K), J1.1, J4.1, J5.1, J8.1, J9.1, U1.8 (V+), U2.1 (IN), U2.3 (EN), U3.8 (V+)
GND: C2.2, C3.2, C4.2, C5.2, C6.2, C7.2, C8.2, C9.2, C10.2, C11.2, C12.2, C13.2, J1.2, J4.2, J4.MP (MountPin), J5.2, J5.MP (MountPin), J8.2, J8.MP (MountPin), J9.2, J9.MP (MountPin), R2.1, R4.1, R8.1, R10.1, U1.4 (V-), U2.2 (GND), U2.4 (NC), U3.4 (V-)
unnamed: C2.1, J2.2, R2.2, R5.1, U1.5 (+)
unnamed: C3.1, J3.2, R4.2, R6.1, U1.3 (+)
unnamed: C9.1, J6.2, R8.2, R11.1, U3.5 (+)
unnamed: C10.1, J7.2, R10.2, R12.1, U3.3 (+)
unnamed: J4.3, R5.2, U1.6 (-), U1.7
unnamed: J5.3, R6.2, U1.1, U1.2 (-)
unnamed: J8.3, R11.2, U3.6 (-), U3.7
unnamed: J9.3, R12.2, U3.1, U3.2 (-)
unnamed: J2.1, R1.1
unnamed: J3.1, R3.1
unnamed: J6.1, R7.1
unnamed: J7.1, R9.1

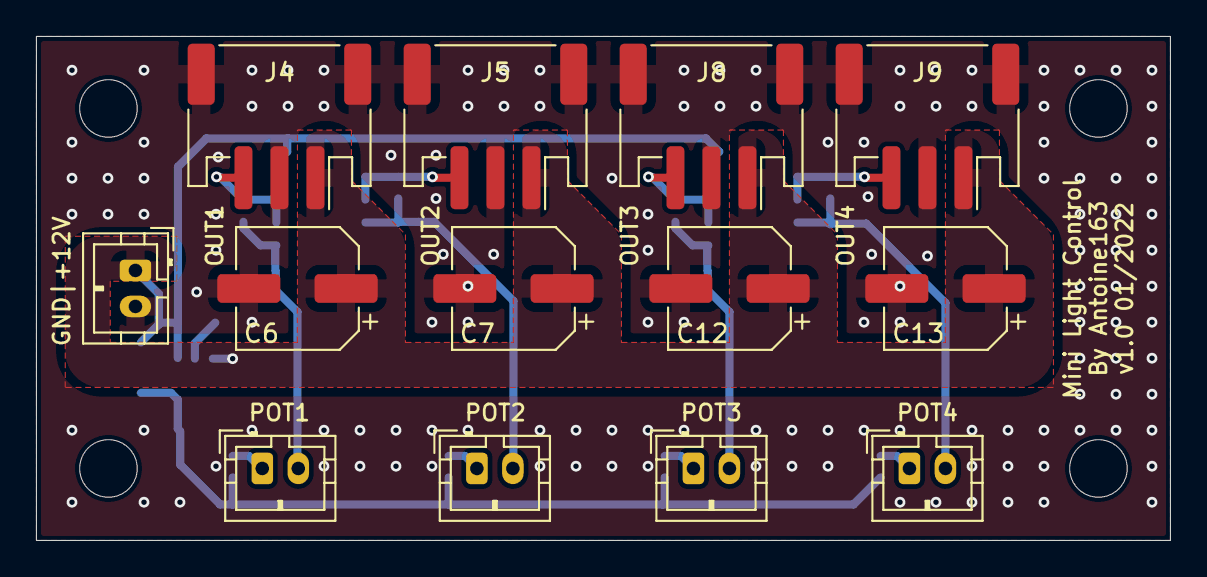
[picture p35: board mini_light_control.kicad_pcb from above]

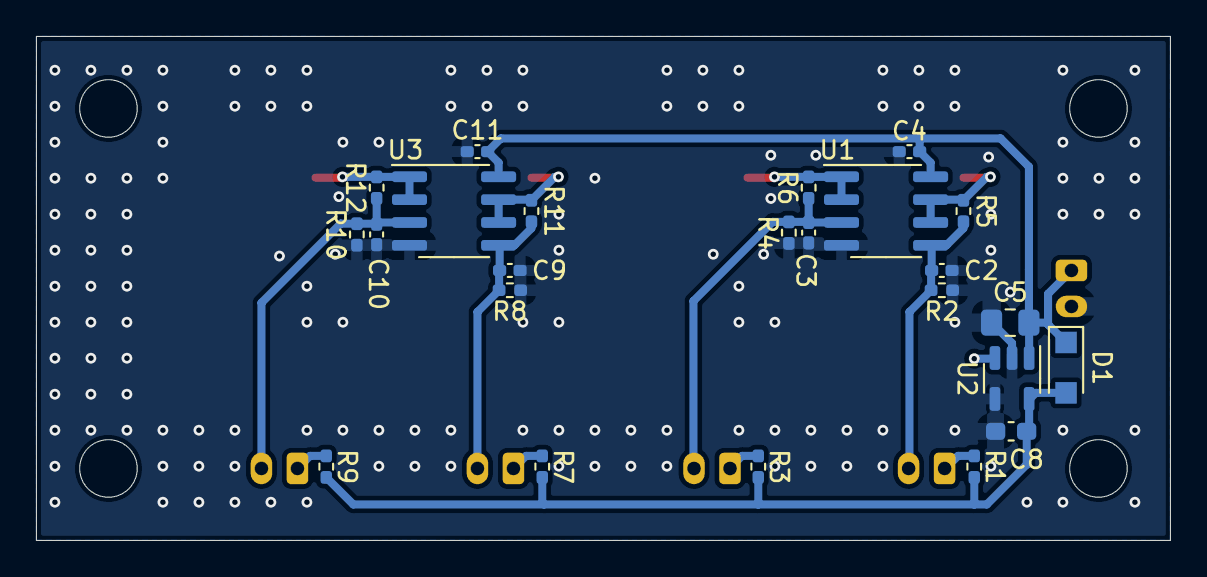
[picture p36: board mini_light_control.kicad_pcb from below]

Board: 2 copper layers, 63.0 x 28.0 mm, 41 parts (24 on the bottom side), 15 nets.

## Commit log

2021-10-05 Add kicad boards
    [mini_light-B_Cu.gbr, mini_light-B_Mask.gbr, mini_light-B_Paste.gbr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]
2021-10-08 Update lib and pcb
    [mini_light-B_Cu.gbr, mini_light-B_Mask.gbr, mini_light-B_Paste.gbr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]
2021-10-10 Add protection diode for LDO and change power connector.
    [mini_light_control-B_Cu.gbr, mini_light_control-B_Mask.gbr, mini_light_control-B_Paste.gbr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]
2021-10-10 Change simbol connector to 'MountingPin' version
    [mini_light_control-B_Cu.gbr, mini_light_control-B_Mask.gbr, mini_light_control-B_Paste.gbr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]
2022-01-04 Change JST connector polarity + regenerate gerber file
    [mini_light-B_Cu.gbr, mini_light-B_Mask.gbr, mini_light-B_Paste.gbr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]
2022-03-13 add Meca folder and some readme
    [J-2835-3D.STEP, RS08U111Z001.STEP, S3B-PH-SM4-TB.step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]
2022-05-21 control_box-AsPotsCap to v2
    [control_box.FCStd]
2022-05-21 Add file of control_box-AsPotsCap_v2
    [control_box-AsPotsCap_v2.3mf, control_box-AsPotsCap_v2.stl]
2022-07-01 Add light_support_for_prusa + pdf elec schematic
    [mini_light.step, support_light_l.3mf, support_light_l.stl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]
2022-10-22 add light_support_for_beam to fix a light on beam
    [support_light.3mf, support_light.FCStd, support_light.stl]
2023-01-14 Add UsbQuickCharge2
    [usb_quick_charge_2.kicad_pcb, usb_quick_charge_2.kicad_sch]
2024-03-17 update 3d step file
    [mini_light.kicad_pcb]
